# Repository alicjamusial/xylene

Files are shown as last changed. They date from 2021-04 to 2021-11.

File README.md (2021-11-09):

# Xylene - DIP-8/16 flash adapter

### ◾ About the project

Xylene is a SPI NOR flash DIP-8/16 adapter with all needed resistors and capacitors. Using it as the wrapper for flash prevents random errors connected to the power supply and ensures proper behavior of the component.

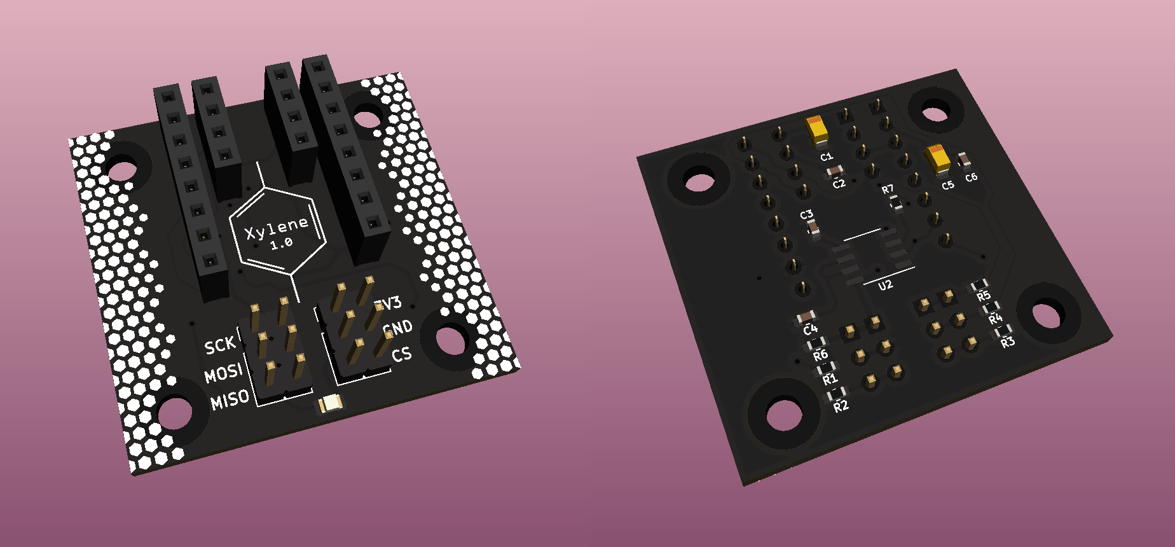
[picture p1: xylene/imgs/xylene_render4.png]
schema


Board was designed using [KiCad 5.1.6](https://kicad.org/).

### ◾ License
Xylene is available on Creative Commons Attribution Share Alike 4.0 International license (more in [license file](LICENSE.txt)). You are free to use it, modify it and produce as many of your own boards as you need :)

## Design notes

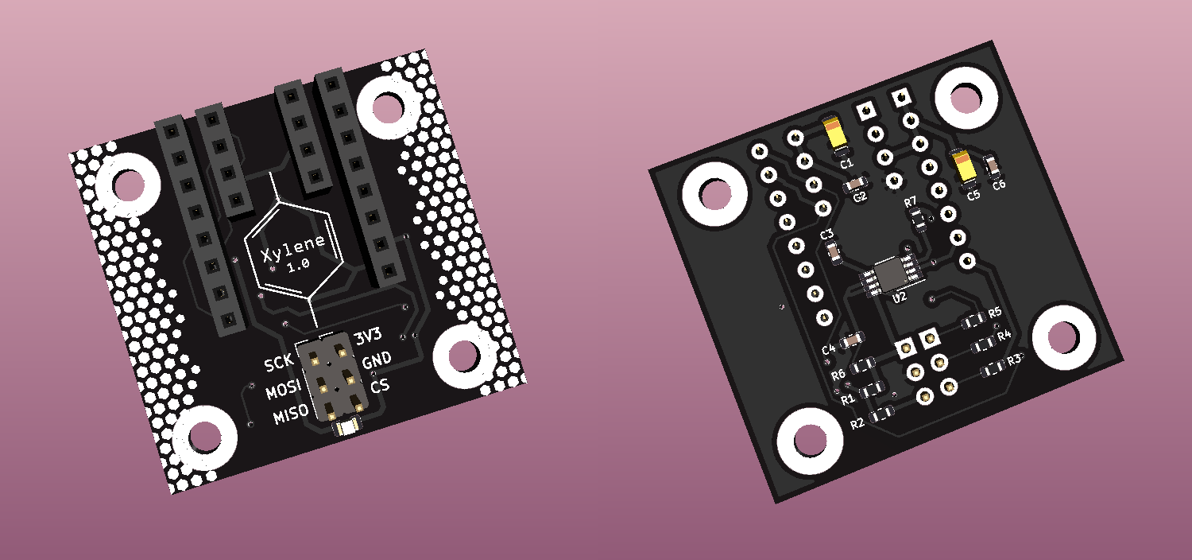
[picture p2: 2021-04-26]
xylene/imgs/xylene_render.png

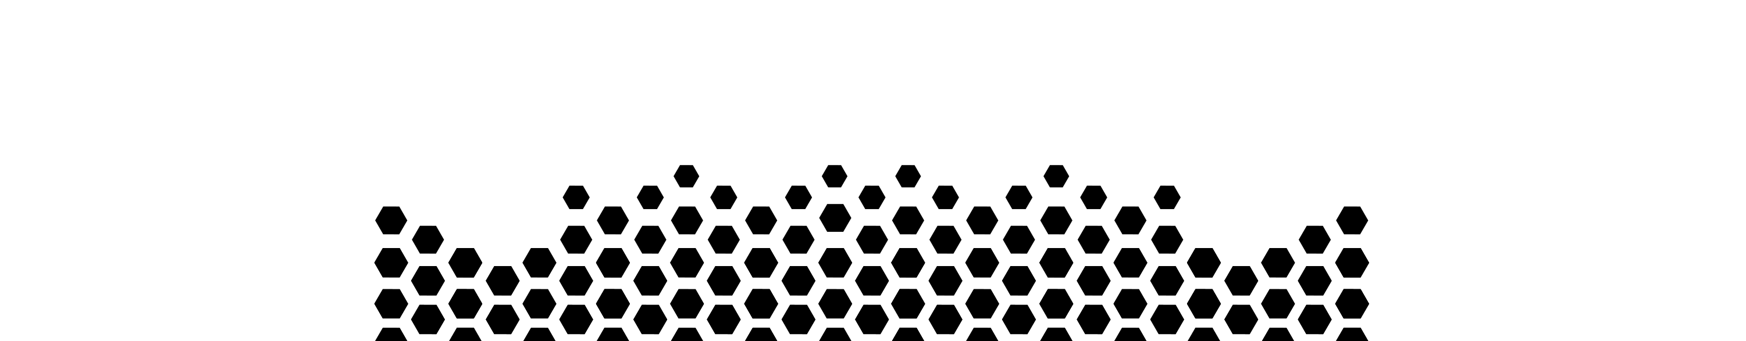
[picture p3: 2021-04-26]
xylene/imgs/wzorek_xylene.png

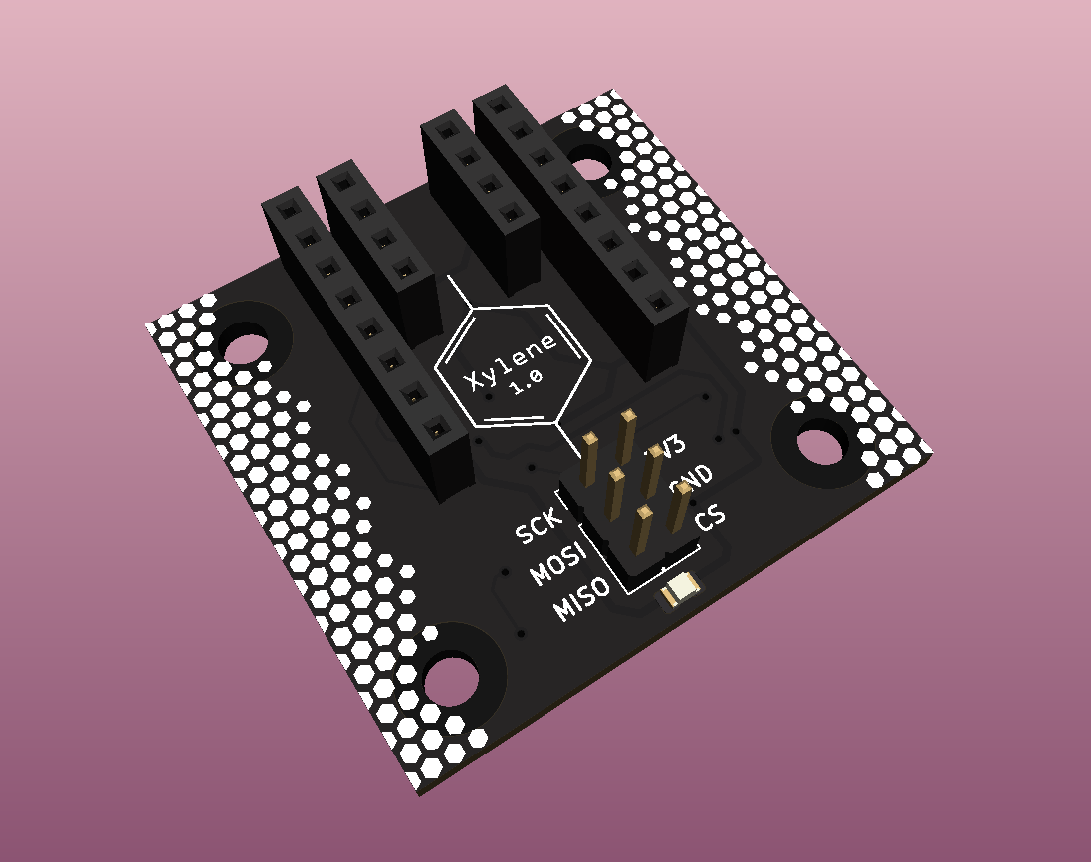
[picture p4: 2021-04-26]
xylene/imgs/xylene_render2.png

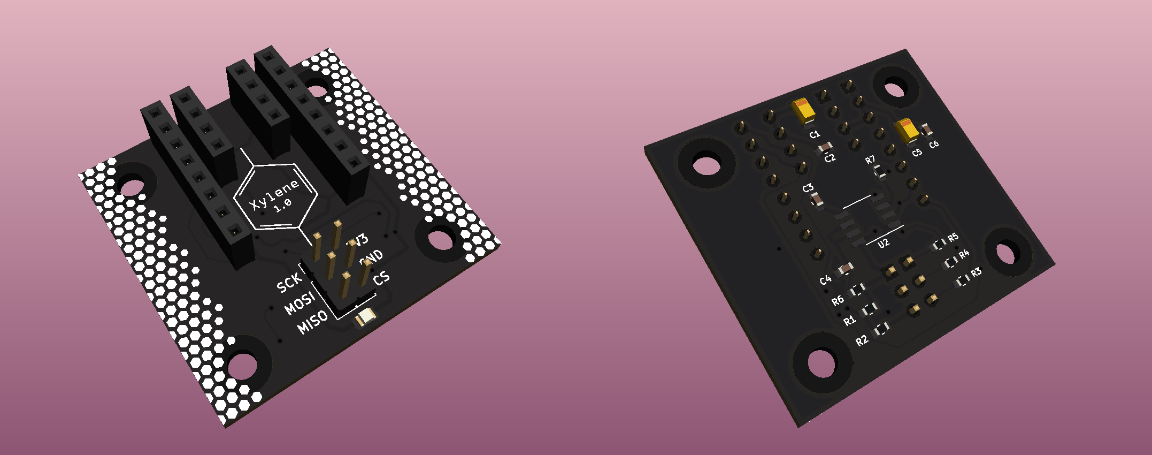
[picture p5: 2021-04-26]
xylene/imgs/xylene_render3.png

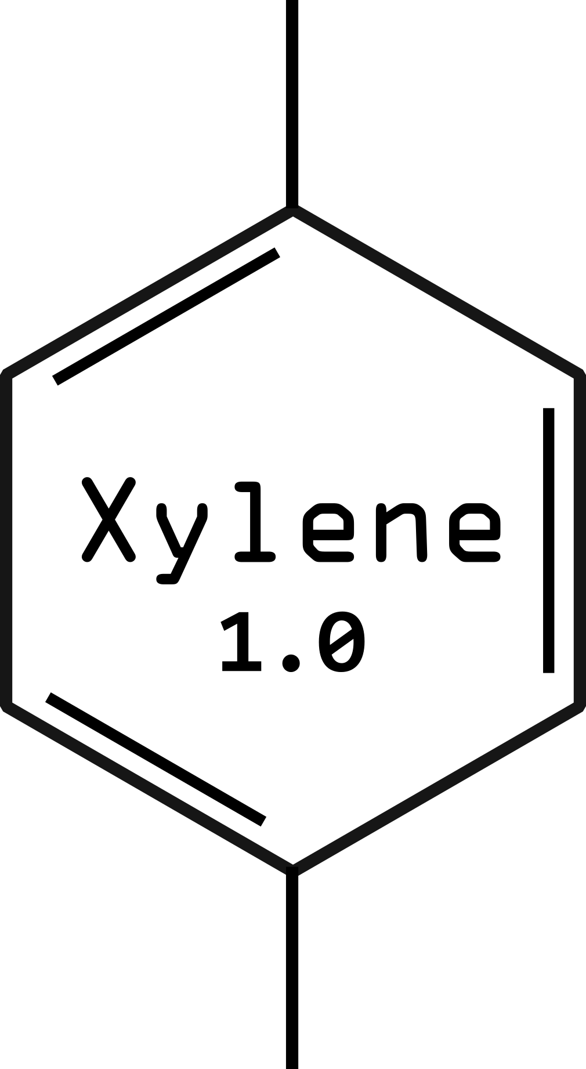
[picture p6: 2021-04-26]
xylene/imgs/xylene.png

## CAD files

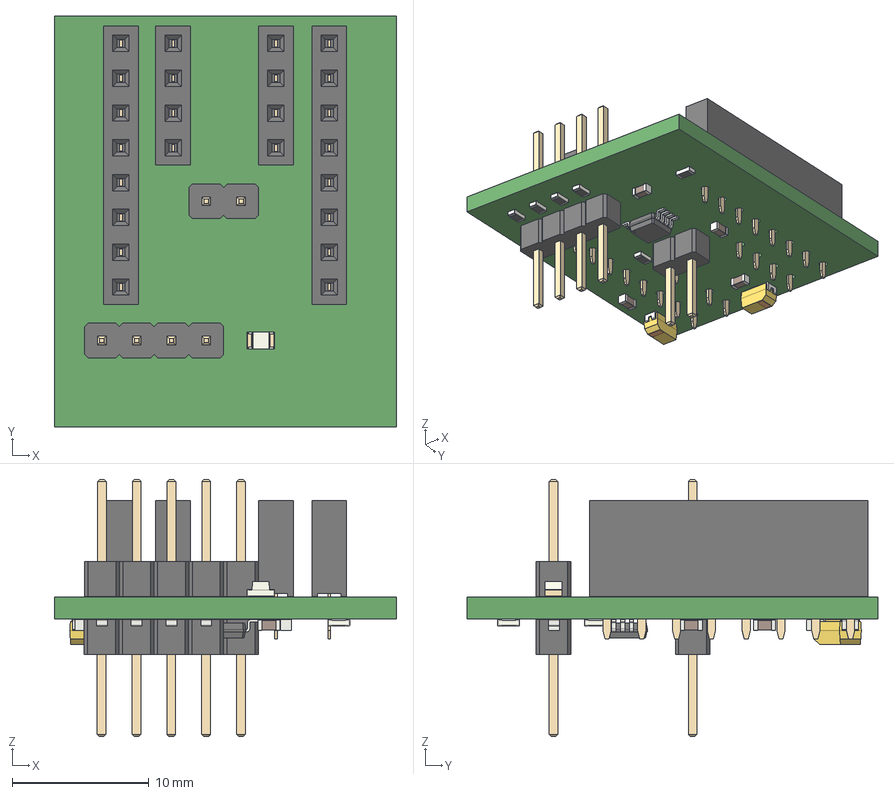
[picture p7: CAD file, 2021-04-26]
xylene/xylene.step
25.0 x 30.0 x 18.8 mm

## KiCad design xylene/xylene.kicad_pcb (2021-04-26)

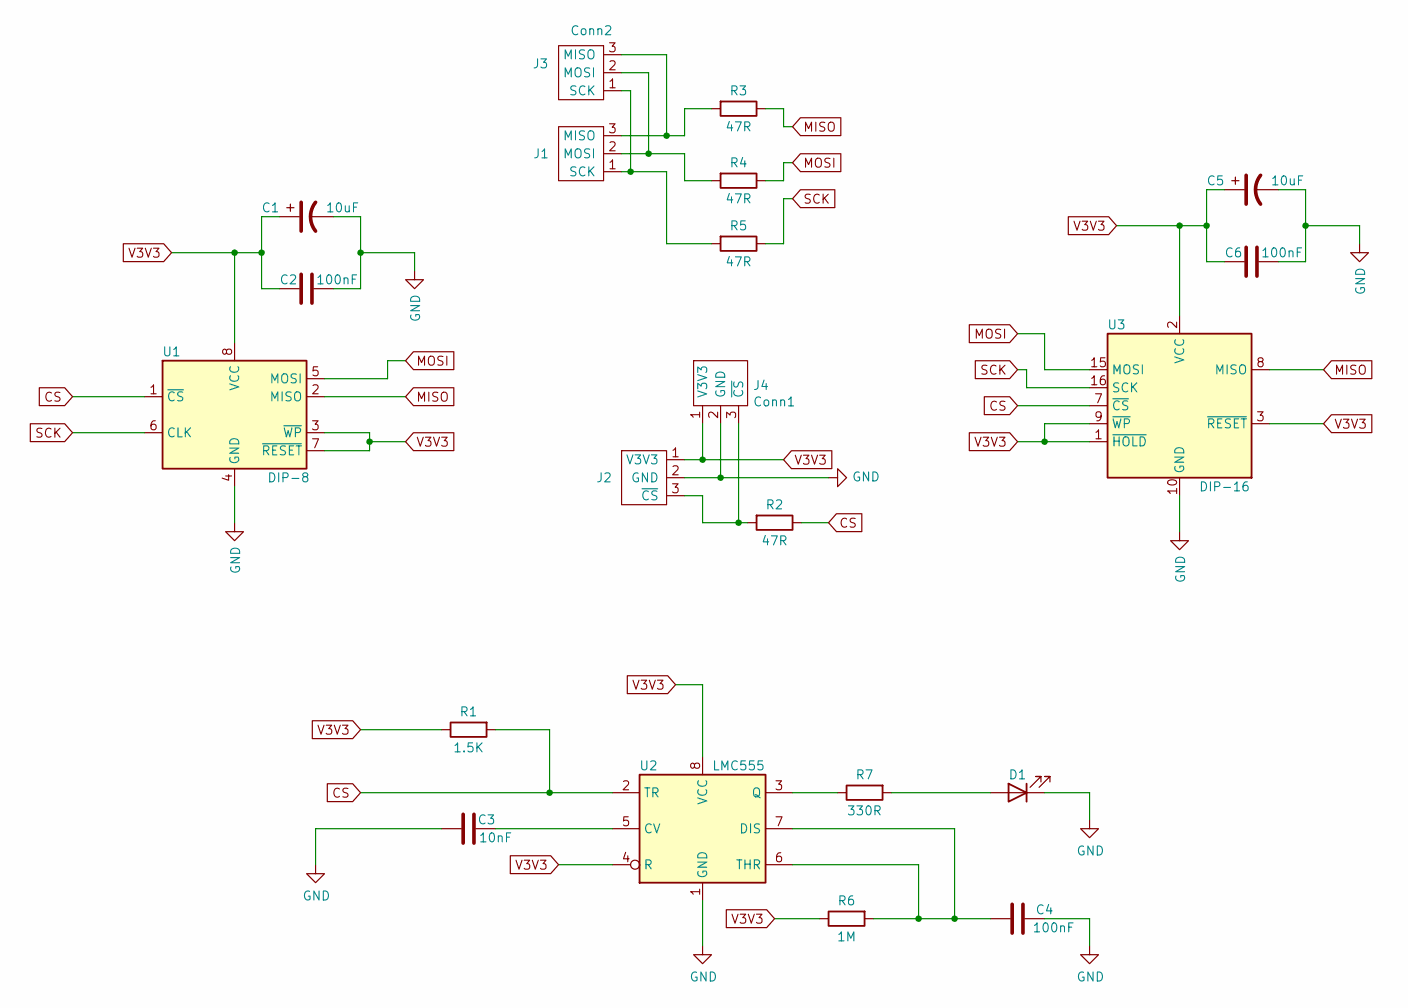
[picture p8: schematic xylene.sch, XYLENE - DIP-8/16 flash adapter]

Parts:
C1, C5: 10uF; CP_EIA-3216-18_Kemet-A
C2, C4, C6: 100nF; C_0603_1608Metric
C3: 10nF; C_0603_1608Metric
D1: LED; LED_0805_2012Metric
J1, J3: Conn2; PinHeader_1x03_P2.54mm_Vertical
J2, J4: Conn1; PinHeader_1x03_P2.54mm_Vertical
R1: 1.5K; R_0603_1608Metric
R2, R3, R4, R5: 47R; R_0603_1608Metric
R6: 1M; R_0603_1608Metric
R7: 330R; R_0603_1608Metric
U1: DIP-8; DIP-8_W7.62mm_Socket_wihtout_lines
U2: LMC555; SO-8_3.9x4.9mm_P1.27mm
U3: DIP-16; DIP-16_W15.24mm_without_lines

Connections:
CS: R1.2, R2.1, U1.1 (~CS), U2.2 (TR), U3.7 (~CS)
GND: C1.2, C2.1, C3.1, C4.2, C5.2, C6.1, D1.1 (K), J2.2 (GND), J4.2 (GND), U1.4 (GND), U2.1 (GND), U3.10 (GND)
MISO: R3.1, U1.2 (MISO), U3.8 (MISO)
MOSI: R4.1, U1.5 (MOSI), U3.15 (MOSI)
unnamed: C3.2, U2.5 (CV)
unnamed: C4.1, R6.2, U2.6 (THR), U2.7 (DIS)
unnamed: D1.2 (A), R7.2
unnamed: J1.1 (SCK), J3.1 (SCK), R5.2
unnamed: J1.2 (MOSI), J3.2 (MOSI), R4.2
unnamed: J1.3 (MISO), J3.3 (MISO), R3.2
unnamed: J2.3 (~CS), J4.3 (~CS), R2.2
unnamed: R7.1, U2.3 (Q)
SCK: R5.1, U1.6 (CLK), U3.16 (SCK)
V3V3: C1.1, C2.2, C5.1, C6.2, J2.1 (V3V3), J4.1 (V3V3), R1.1, R6.1, U1.3 (~WP), U1.7 (~RESET), U1.8 (VCC), U2.4 (R), U2.8 (VCC), U3.1 (~HOLD), U3.2 (VCC), U3.3 (~RESET), U3.9 (~WP)

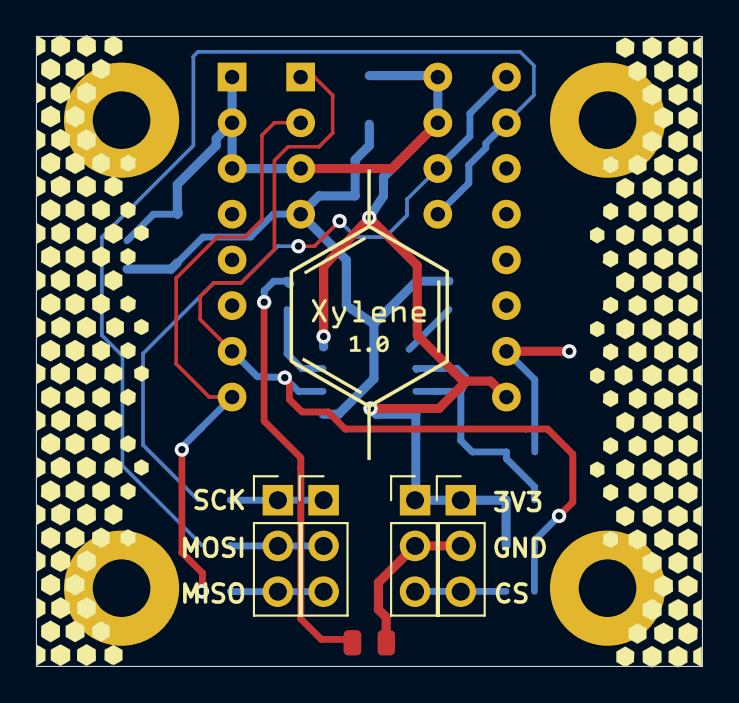
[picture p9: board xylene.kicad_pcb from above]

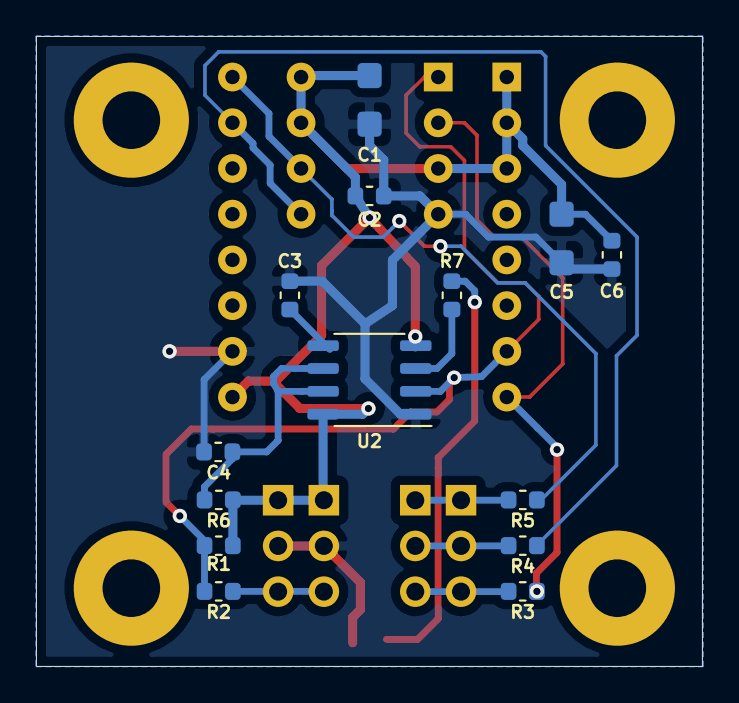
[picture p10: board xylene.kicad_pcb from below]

Board: 2 copper layers, 37.0 x 35.0 mm, 21 parts (14 on the bottom side), 14 nets.

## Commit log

2021-04-26 Xylene - repo init
    [ksylen.kicad_pcb, ksylen.sch, ksylen.step]
2021-04-26 Add holes
    [ksylen.kicad_pcb]
2021-04-26 All components
    [ksylen.kicad_pcb]
2021-04-26 Rename project & add readme
    [xylene.kicad_pcb, xylene.sch, xylene.step]
2021-04-26 Change 555 to SO-8
    [xylene.kicad_pcb, xylene.sch]
2021-04-26 Add renders
    [xylene.kicad_pcb]
2021-04-26 Add second pins for logic analyzer
    [xylene.kicad_pcb, xylene.sch]
2021-04-26 Clean images
    [xylene.kicad_pcb]
2021-11-08 Update README.md
    https://forum.kicad.info/t/warning-avoid-all-links-to-kicad-pcb-org-use-kicad-org/31521
